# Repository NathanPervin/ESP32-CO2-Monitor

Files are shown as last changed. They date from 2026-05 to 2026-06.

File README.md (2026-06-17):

# CO2 Monitor
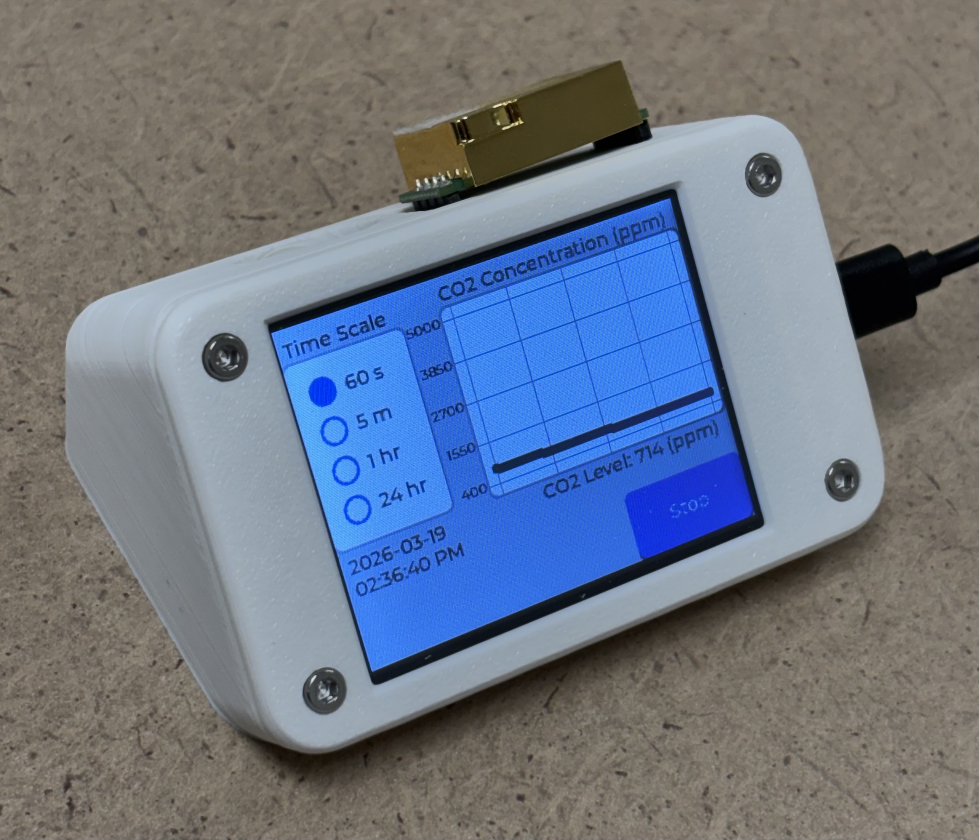
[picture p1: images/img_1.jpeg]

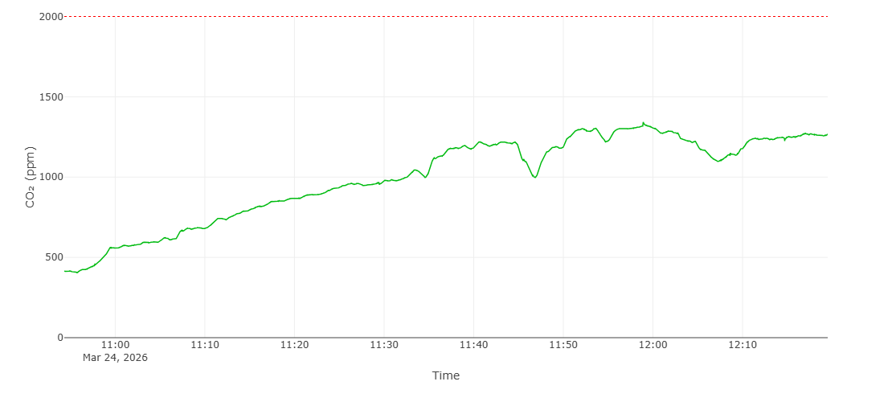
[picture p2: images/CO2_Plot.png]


### Description
An ESP32-based CO2 monitor that logs readings to a SQLite database and displays them through a Django web application.

### Impact
[Studies](https://www.sciencedirect.com/science/article/pii/S036013232300358X) have shown that short-term exposure to high levels of CO2 can reduce cognitive performance and negatively impact learning. Therefore, it is important to be ensure that CO2 levels remain low in an academic setting.

### Components
MH-Z19C CO2 Sensor ([more info](https://www.winsen-sensor.com/d/files/infrared-gas-sensor/mh-z19c-pins-type-co2-manual-ver1_0.pdf)) \
[by EC Buying](https://www.amazon.com/EC-Buying-Monitoring-Concentration-Detection/dp/B0CRKH5XVX)

ESP32 Cheap Yellow Display ([more info](https://www.lcdwiki.com/2.8inch_ESP32-32E_Display))\
[by Hosyond](https://www.amazon.com/gp/product/B0D92C9MMH)

### Features
* Screen automatically sleeps after 5 minutes of inactivity
* Zero the CO2 sensor to 400 ppm by depressing the button for 7 seconds (only do this when outdoors)

### Dependencies
* Django for web app, API endpoint, and SQLite database
* LVGL for ESP-32 GUI
* TFT_eSPI
* XPT2046_Touchscreen
ESP32 CYD GUI configuration files can be found in [this guide](https://randomnerdtutorials.com/lvgl-cheap-yellow-display-esp32-2432s028r)

### Data Collection and Upload

Samples will be taken every 1 second. The timestamp will be updated after each data POST request to keep the timestamps accurate over long periods of time. POST requests will be made every 4 minutes to reduce power usage and live data is already displayed on the CYD. A SQLite database hosted in the cloud will be used to store the data.

#### `POST /api/log/`

Logs one or more CO2 readings to the database.

**Authentication:** Bearer token via `Authorization` header (set `CO2_API_TOKEN` in `.env`)

**Request body:** A single JSON object or an array of objects:
```json
[
  {"mode": "ambient", "building": "COE", "room_number": 306, "unix_timestamp": 1678886400, "CO2_ppm": 750},
  {"mode": "ambient", "building": "COE", "room_number": 306, "unix_timestamp": 1678886401, "CO2_ppm": 760}
]
```

| Field | Type | Max Length | Description |
|---|---|---|---|
| `mode` | string | 50 chars | `"ambient"` or `"session"` |
| `building` | string | 30 chars | Building identifier (e.g. `"COE"`) |
| `room_number` | string | 10 chars | Room number (e.g. "301A")|
| `unix_timestamp` | int |  | Unix timestamp of the reading |
| `CO2_ppm` | int |  | CO2 concentration in parts per million |

**Responses:**

| Status | Meaning |
|---|---|
| `201` | Success — returns `{"success": true, "records_saved": N}` |
| `400` | Malformed JSON or missing field |
| `401` | Missing or invalid token |

### Pinout
| Pin | Use |
|-----|-----|
| IO35 | PWM for CO2 Sensor |
| 5V (UART PORT) | Vin for CO2 Sensor |
| GND | GND for CO2 Sensor |
| GND | GND for button -> CO2 Sensor HD Pin |

### CAD
Modified [ghfisanotti's CYD Case on Thingiverse](https://www.thingiverse.com/thing:7047135), licensed under CC BY-SA 3.0. See CAD folder in this repo for the STL and STEP files. 

### Required Parts and Assembly
* 1x ESP-32 CYD
* 1x MH-Z19C CO2 Sensor
* 2x 1.25mm 4-pin JST to Dupont connectors
* 1x CYD_LID (3D printed)
* 1x CYD_BASE (3D printed)
* 4x M3 heat-set inserts
* 4x M3x8 bolts
* 1x [push button](https://www.amazon.com/Waterproof-Momentary-Button-Switch-Colors/dp/B07F24Y1TB) *optional, for zeroing the sensor
* 1x 5-pin female pin header *optional, for securing the sensor to the base

The 5-pin female pin header is secured by melting the plastic around it with a soldering iron. On the female pin header that the MH-Z19C's HD pin will plug into, solder a wire (this will connect to one pin of the button). Connect the other pin of the button to a GND pin on the CYD.

###  How to run
Clone this repo
```bash
git clone https://github.com/NathanPervin/ESP32-CO2-Monitor.git
```
```bash
cd ESP32-CO2-Monitor
```

Create a virtual environment
```bash
python -m venv venv
```

Start virtual environment
```bash
source venv/bin/activate
```

Install dependencies
```bash
pip install -r requirements.txt
```

Set environment variables in the file Django/CO2_Dashboard/.env, see the .env.example file in that directory for the required variables. Also set the environment variables in testing/.env, see the .env.example file in that folder for the required variables.

To Generate the CO2_API_TOKEN SECRET_KEY you can run the following command twice:
```bash
python -c "import secrets; print(secrets.token_urlsafe(50))"
```
The CO2_API_TOKEN in this .env and in the esp32 secrets.h must match. 

```bash
cd Django
```
create the database tables
```bash
python manage.py migrate
```

Make your account (use these credentials to sign in). To make a standard user account, see the `Miscellaneous Info` section in this document.
```bash
python manage.py createsuperuser
```

Run locally using:
```bash
python manage.py runserver 0.0.0.0:8000
```

If hosting use the following commands:
```bash
python manage.py collectstatic --noinput
```

Create a systemd service so the web app automatically starts on boot.
```bash
sudo nano /etc/systemd/system/co2dashboard.service
```

Copy and Paste (right click), then change the WorkingDirectory to reflect your system's file path. Exit using CTRL+X then `y`, then hit enter.
```
[Unit]
Description=CO2 Dashboard
After=network.target

[Service]
User=root
WorkingDirectory=/path/to/ESP32-CO2-Monitor/Django
ExecStart=/path/to/ESP32-CO2-Monitor/venv/bin/gunicorn
CO2_Dashboard.wsgi:application --bind 127.0.0.1:8000 --workers 1
Restart=always

[Install]
WantedBy=multi-user.target
```
if you are a different linux user than `root`, replace `root` above with the output of `whoami`

Enable and start systemd service:
```bash
sudo systemctl daemon-reload
```

```bash
sudo systemctl enable co2dashboard
```

```bash
sudo systemctl start co2dashboard
```

Check if its running:
```bash
sudo systemctl status co2dashboard
```

Use caddy as a reverse proxy (requires a domain)
```bash
sudo apt update
```

Install [caddy](https://caddyserver.com/docs/install#debian-ubuntu-raspbian)
```bash
sudo apt install -y debian-keyring debian-archive-keyring apt-transport-https curl
curl -1sLf 'https://dl.cloudsmith.io/public/caddy/stable/gpg.key' | sudo gpg --dearmor -o /usr/share/keyrings/caddy-stable-archive-keyring.gpg
curl -1sLf 'https://dl.cloudsmith.io/public/caddy/stable/debian.deb.txt' | sudo tee /etc/apt/sources.list.d/caddy-stable.list
sudo chmod o+r /usr/share/keyrings/caddy-stable-archive-keyring.gpg
sudo chmod o+r /etc/apt/sources.list.d/caddy-stable.list
sudo apt update
sudo apt install caddy
```

Write the Caddyfile:
```bash
nano /etc/caddy/Caddyfile
```

Copy and Paste (right click), then change the example.com domain to your domain, as well as the file path to your system's path to the staticfiles directory within the Django project. Exit using CTRL+X then `y`, then hit enter.
```
example.com {
    handle /static/* {
        uri strip_prefix /static
        root * /path/to/ESP32-CO2-Monitor/Django/staticfiles
        file_server
    }
    reverse_proxy localhost:8000
}
```

restart Caddy
```bash
sudo systemctl reload caddy
```

Remember to update your domain's DNS records to your server's IP. Also ensure your firewall settings allow access to ports 80 (http) and 443 (https), which Caddy listens on by default.

### How to set up ESP32 CYD
Instructions are for the Arduino IDE:

Open the `esp32/CO2Monitor.ino` file in the Arduino IDE.

install the following libraries from the Library Manager within the Arduino IDE:
* `TFT_eSPI` by `Bodmer`
* `XPT2046_Touchscreen` by `Paul Stoffregen`
* `lvgl` by `kiskegabor`

Follow [this tutorial](https://randomnerdtutorials.com/lvgl-cheap-yellow-display-esp32-2432s028r/), just the `Prepare Config Files for TFT_eSPI and LVGL Library` section is required. 

Then, download the program to your esp32.

### Unit Testing
Run the external API unit tests
```bash
cd testing
```
```bash
pytest testing_api.py 
```

Run the Django internal unit tests
```bash
cd Django/
```
```bash
python manage.py test api -v 2
```

### Miscellaneous Info
Create User
```bash
python manage.py shell
```
```bash
from django.contrib.auth.models import User
```

```bash
User.objects.create_user(username='myuser', password='mypassword')
```

Delete User
```bash
User.objects.get(username='myuser').delete()
```

Change `DEFAULT_BUILDING` and `DEFAULT_ROOM` in secrets.h to simply press start to log data for that room without needing to type it in.

CO2 values are POSTed every 240 seconds (4 minutes) with 240 samples. Increasing the number of samples in each POST can cause the POSTs to fail with the serial log of:
```
POST failed: connection refused
```
If you get this error, try to reduce the number of samples sent in each POST by changing the value of `LOG_BUFFER_SIZE` in `esp32/CO2Monitor.ino`.

If you are using GitHub and want the actions to work properly, add your CO2_API_TOKEN and SECRET_KEY (same as your .env file) to your GitHub repository's secrets.

#### Testing Database Entry Labels
* building of 'debug', room 0 for esp32 test insertions (unless overridden in secrets.h)
* building of 'debug', room 1 for unit testing

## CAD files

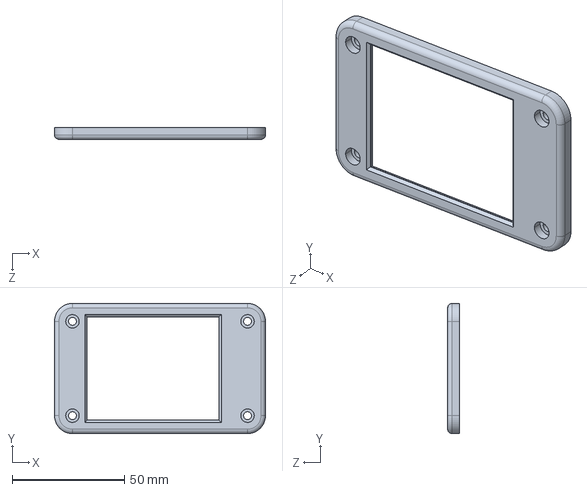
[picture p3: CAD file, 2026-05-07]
CAD/CYD_LID.STEP
94.0 x 58.0 x 5.20 mm

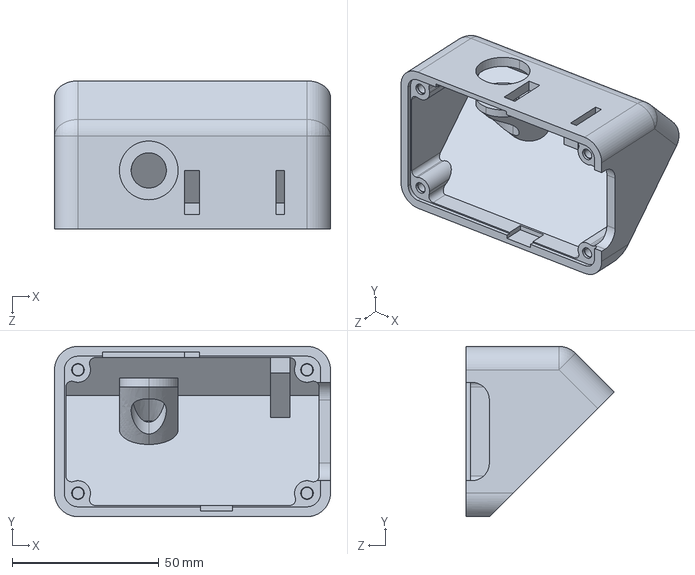
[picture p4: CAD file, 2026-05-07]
CAD/CYD_BASE.STEP
94.0 x 58.0 x 50.5 mm

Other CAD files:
CAD/CYD_BASE.STL
CAD/CYD_LID.STL

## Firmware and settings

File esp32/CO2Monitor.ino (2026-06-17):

// GUI:
// Configuration files and base code from: https://randomnerdtutorials.com/lvgl-cheap-yellow-display-esp32-2432s028r
// LVGL documentation: https://docs.lvgl.io/

// includes for GUI
#include <lvgl.h>
#include <TFT_eSPI.h>
#include <XPT2046_Touchscreen.h>

// includes for WIFI
#include <WiFi.h>
#include <time.h>
#include <secrets.h>
#include <HTTPClient.h>
#include <WiFiClientSecure.h>

/*
    GUI Variables
*/
// Touchscreen pins
#define XPT2046_IRQ 36   // T_IRQ
#define XPT2046_MOSI 32  // T_DIN
#define XPT2046_MISO 39  // T_OUT
#define XPT2046_CLK 25   // T_CLK
#define XPT2046_CS 33    // T_CS

#define TFT_BL 21 // backlight

SPIClass touchscreenSPI = SPIClass(VSPI);
XPT2046_Touchscreen touchscreen(XPT2046_CS, XPT2046_IRQ);

#define SCREEN_WIDTH 240
#define SCREEN_HEIGHT 320

// Touchscreen coordinates: (x, y) and pressure (z)
int x, y, z;

#define DRAW_BUF_SIZE (SCREEN_WIDTH * SCREEN_HEIGHT / 10 * (LV_COLOR_DEPTH / 8))
uint32_t draw_buf[DRAW_BUF_SIZE / 4];

const char* top_text = "CO2 Monitor";
const char* enter_building_text = "Building";
const char* enter_room_number_text = "Room Number";
const char* ambient_text = "Ambient";
const char* session_text = "Session";
const char* CO2_plot_title = "CO2 Concentration (ppm)";
const char* time_scale_text = "Time Scale";

bool is_ambient = true; // default value is to record as an ambient, if false, mode is session

static lv_obj_t* start_screen;
static lv_obj_t* recording_screen;

static lv_obj_t * ta1; // text area for the building input
static lv_obj_t * ta2; // text area for the room input

#define MAX_BUILDING_LENGTH 31  
#define MAX_ROOM_LENGTH 11      

//#define MAX_INPUT_TEXT_LENGTH 50
char building_text[MAX_BUILDING_LENGTH];
char room_text[MAX_ROOM_LENGTH];

static lv_obj_t * chart;
static lv_chart_series_t * ser;

// the width of the x axis, in seconds 
static short int time_scale = 60; 

// determines how many point will be displayed at once,
const short int number_plot_points = 60; 
const short int CO2_plot_rate = 1000; // ms
static short int CO2_min = 400; // ppm
static short int CO2_max = 5000; // ppm

static lv_style_t style_radio;
static lv_style_t style_radio_chk;

const char* time_scales[] = {
  "60 s",
  "5 m",
  "1 hr",
  "24 hr",
  NULL
};

typedef enum {
  t_60s,
  t_5mins,
  t_1hr,
  t_24hrs
} TimeScale;

TimeScale current_time_scale = t_60s;

const int screen_sleep_after_time = 300000; // ms, 5 mins

lv_obj_t * CO2_level_label;
char CO2_level_text[30];

lv_obj_t * time_label;
char time_text[32];

lv_obj_t * error_label;
char error_text[32];

lv_obj_t * wifi_dropdown = NULL;
lv_obj_t * wifi_icon_button;

/*
//  CO2 Sensor Variables
*/
#define CO2_PWM_PIN 35

volatile unsigned long previous_low_start = 0;  // us
volatile unsigned long previous_high_start = 0; //us
volatile unsigned long TL = 0; // us
volatile unsigned long TH = 0; // us

const short int CO2_log_rate = 1000; // ms

/*
    WIFI Variables
*/
const char* ntpServer = "pool.ntp.org";
const long gmtOffset_sec = -18000;   // EST
const int daylightOffset_sec = 3600;  // 1 hour for daylight saving
bool wifi_initialized = false;

unsigned long last_wifi_init_attempt = 0; // timestamp of last attempt
const unsigned long attempt_wifi_init_every = 5000; // ms
static int max_init_attempts = 5;

#define MAX_SSID_LEN 64
#define MAX_PASSWORD_LEN 64

char WIFI_SSID[MAX_SSID_LEN];
char WIFI_PASSWORD[MAX_PASSWORD_LEN];

/*
    System Variables
*/
// buffers that will store the last 60 points
// which are an average of the available time intervals
static int32_t buffer_60secs[number_plot_points];
static int32_t buffer_5min[number_plot_points];
static int32_t buffer_1hr[number_plot_points];
static int32_t buffer_24hrs[number_plot_points];

// store the index where the next value should be placed
int i_60secs = 0;
int i_5mins = 0;
int i_1hr = 0;
int i_24hrs = 0;

// variables to find the average CO2 ppm over an interval
float sum_last_5s_CO2 = 0;
float count_5s = 0;
float sum_last_60s_CO2 = 0;
float count_60s = 0;
float sum_last_1440s_CO2 = 0;
float count_1440s = 0;

const short int ppm_threshold = 2000; // CO2 ppm above this will make the plot line red
static float CO2_value = 0;

bool on_start_screen = false;
bool on_recording_screen = false;

#define LOG_BUFFER_SIZE 240 // 240 JSON lines, 1s per line = 240 minutes of data

// {"mode":"session","building":"","room_number":"","unix_timestamp":1700000000,"CO2_ppm":5000}
// fixed chars:  ~64  +  max building: 30  +  max room: 10  +  null: 1  =  105, use 128 for extra room
#define MAX_JSON_LINE 128
char log_buffer[LOG_BUFFER_SIZE][MAX_JSON_LINE];
int log_buffer_index = 0;

/*
    CO2 Sensor Functions
*/
// Software interrupt on IO35 Change
void ARDUINO_ISR_ATTR read_PWM() {

  // Get level to determine if the ISR was triggered on rising on falling edge
  int level = digitalRead(CO2_PWM_PIN);

  // get the current microseconds since program start or last overflow
  unsigned long now = micros(); 

  // rising edge, the duration of the low time can be calculated by
  // subtracting the previous falling edge's time from the current time
  if (level == HIGH) {
    TL = now - previous_low_start;
    previous_high_start = now;
  } else { 
    // falling edge, the duration of the high time preceding this can be found by 
    // subtracting the previous rising edge's time from the current time
    TH = now - previous_high_start;
    previous_low_start = now;
  }
}

/*
    WIFI Functions
*/
// connects to wifi and configures NTP for unix time retrieval
void initialize_wifi() {
  Serial.printf("Connecting to Wi-Fi %s ...\n", WIFI_SSID);

  // SSID and password must be inside of secrets.h
  WiFi.begin(WIFI_SSID, WIFI_PASSWORD);

  // try to connect to the wifi
  int attempts = 0;
  while (WiFi.status() != WL_CONNECTED && attempts < max_init_attempts) {
    delay(500);
    Serial.print(".");
    attempts++;
  }

  if(WiFi.status() != WL_CONNECTED){
    Serial.println("\nFailed to connect to Wi-Fi");
    wifi_initialized = false;
    error_handler();
    return;
  } 
  else {
    wifi_initialized = true;
    error_handler();
  }

  Serial.println("\nWi-Fi connected!");
  wifi_initialized = true;
  Serial.print("IP address: ");
  Serial.println(WiFi.localIP());

  // Initialize NTP
  configTime(gmtOffset_sec, daylightOffset_sec, ntpServer);
}

// Handles wifi connection attempts if wifi connection fails,
// attempts to estabish a new connection on set intervals until
// a successful connection is made
bool handle_wifi_reinitialization() {
  if (!wifi_initialized) {

    // check that the time interval between connections has passed
    if (millis() - last_wifi_init_attempt >= attempt_wifi_init_every) {
      
      initialize_wifi();
      last_wifi_init_attempt = millis(); // reset timestamp
      return wifi_initialized;
    }
    else { // time interval for new connection attempt has no yet passed
      return false;
    }
  } // wifi is already initialized
  return true;
}

// returns the unix time 
time_t get_unix_time() {

  // if the wifi is not connected, then the unix time cannot be establisheds
  if (!handle_wifi_reinitialization()) return -1;

  time_t now = time(nullptr);
  int retry = 0;
  const int retry_count = 10;

  // ensure unix time is valid, otherwise try again
  while (now < 1000000000 && retry < retry_count) { 
    delay(500);
    now = time(nullptr);
    retry++;
  }

  if(now < 1000000000) return 0;
  return now;
}

/*
    System Functions
*/
// saves a CO2 level and unix timestamp to a JSON string and adds it to the buffer 
// that stores all of the JSON lines prior to sending the POST request
// also calls function that will POST when buffer is full
void log_data(int32_t CO2_ppm, time_t unix_time) {

  // synthesize the JSON string that will be stored in the buffer 
  snprintf(log_buffer[log_buffer_index], MAX_JSON_LINE,
    "{\"mode\":\"%s\",\"building\":\"%s\",\"room_number\":\"%s\",\"unix_timestamp\":%ld,\"CO2_ppm\":%d}",
    is_ambient ? "ambient" : "session",
    building_text,
    room_text,
    (long)unix_time,
    (int)CO2_ppm
  );

  // each time a line is added to the buffer, increment a counter and
  // call function to POST the data when the buffer is full
  log_buffer_index++;
  if (log_buffer_index >= LOG_BUFFER_SIZE) {
    upload_data();
    log_buffer_index = 0;
  }
}

// makes the POST request to the SERVER_URL in secrets.h
// handles inputting the api token into the header for authentification
bool upload_data() {

  // ensure that wifi is connected
  if (!handle_wifi_reinitialization()) {
    Serial.println("Cannot upload: WiFi not connected");
    return false;
  }

  // calculate payload size upfront to avoid reallocation
  int payload_len = 2; // [ ]
  for (int i = 0; i < log_buffer_index; i++) {
    payload_len += strlen(log_buffer[i]);
    if (i < log_buffer_index - 1) payload_len += 1; // comma
  }

  String payload;
  payload.reserve(payload_len + 1);
  payload = "[";
  for (int i = 0; i < log_buffer_index; i++) {
    payload += log_buffer[i];
    if (i < log_buffer_index - 1) payload += ",";
  }
  payload += "]";

  WiFiClientSecure client;
  client.setInsecure();
  HTTPClient http;
  http.begin(client, SERVER_URL);
  http.addHeader("Content-Type", "application/json");
  http.addHeader("Authorization", "Bearer " + String(API_TOKEN));

  Serial.printf("Uploading %d readings...\n", log_buffer_index);
  int response_code = http.POST(payload);

  if (response_code > 0) {
    Serial.printf("POST response: %d\n", response_code);
    Serial.println(http.getString());
    http.end();
    return true;
  } else {
    Serial.printf("POST failed: %s\n", http.errorToString(response_code).c_str());
    http.end();
    return false;
  }
}

// called each time a CO2 value is collected (every 1 second),
// values get averaged and stored in all buffers to allow for
// past data to be displayed for new timescale 
void load_buffers(float CO2_ppm) {
  
  int32_t val = (int32_t)CO2_ppm;
  time_t time = get_unix_time();

  // display nothing to the user if time is not valid
  // usually when wifi isn't initialized yet
  if (time == -1 || time == 0) {
    snprintf(time_text, sizeof(time_text), "");
  } 
  else {
    convert_time(time); // saves time to global var time_text

    // only log the value if we are able to receive a time stamp
    log_data(val, time);
  }

  // load 60 seconds buffer, get next index
  buffer_60secs[i_60secs] = val;
  i_60secs = (i_60secs + 1) % number_plot_points; // index of 60 loops back to 0

  // avoid duplicate plot updates
  if (current_time_scale == t_60s) {
    update_plot();
  }

  // calculate sums and advance counters
  sum_last_5s_CO2 += CO2_ppm;
  count_5s++;
  sum_last_60s_CO2 += CO2_ppm;
  count_60s++;
  sum_last_1440s_CO2 += CO2_ppm;
  count_1440s++;

  // push the last 5 second average into the 5 minute buffer 
  if(count_5s >= 5) {

    int32_t avg = (int32_t)(sum_last_5s_CO2 / count_5s);

    // load buffer, get next index 
    buffer_5min[i_5mins] = avg;
    i_5mins = (i_5mins + 1) % number_plot_points;

    sum_last_5s_CO2 = 0;
    count_5s = 0;
    update_plot();
  }

  // push the last 60 second average into the 1 hour buffer 
  if(count_60s >= 60) {

    int32_t avg = (int32_t)(sum_last_60s_CO2 / count_60s);

    // load buffer, get next index 
    buffer_1hr[i_1hr] = avg;
    i_1hr = (i_1hr + 1) % number_plot_points;

    sum_last_60s_CO2 = 0;
    count_60s = 0;
    update_plot();
  }

  // push the last 1440 second average into the 24 hour buffer 
  if(count_1440s >= 1440) {

    int32_t avg = (int32_t)(sum_last_1440s_CO2 / count_1440s);

    // load buffer, get next index 
    buffer_24hrs[i_24hrs] = avg;
    i_24hrs = (i_24hrs + 1) % number_plot_points;

    sum_last_1440s_CO2 = 0;
    count_1440s = 0;
    update_plot();
  }

}

// clears all buffers and related variables
// used when user creates a new recording session
void clear_buffers() {

  // initialize the buffers so that the plot will be empty on start
  for(int i = 0; i < number_plot_points; i++) {
    buffer_60secs[i] = LV_CHART_POINT_NONE;
    buffer_5min[i] = LV_CHART_POINT_NONE;
    buffer_1hr[i] = LV_CHART_POINT_NONE;
    buffer_24hrs[i] = LV_CHART_POINT_NONE;
  }

  i_60secs = 0;
  i_5mins = 0;
  i_1hr = 0;
  i_24hrs = 0;

  sum_last_5s_CO2 = 0;
  count_5s = 0;
  sum_last_60s_CO2 = 0;
  count_60s = 0;
  sum_last_1440s_CO2 = 0;
  count_1440s = 0;

  log_buffer_index = 0;

}

// Gets the building and room number text from the text areas, checks that the they are valid
bool get_location() {
  const char* building_text_const = lv_textarea_get_text(ta1); 
  const char* room_text_const = lv_textarea_get_text(ta2); 

  // enforce maximum building and room length in case lvgl max
  // input limit fails to avoid buffer overflow when creating JSON lines
  if (strlen(building_text_const) >= MAX_BUILDING_LENGTH) {
    Serial.println("Error: Building name too long!");
    return false;
  }
  if (strlen(room_text_const) >= MAX_ROOM_LENGTH) {
    Serial.println("Error: Room number too long!");
    return false;
  }

  // if no building was entered, use the default from secrets.h
  if (strlen(building_text_const) == 0) {
    strncpy(building_text, DEFAULT_BUILDING, MAX_BUILDING_LENGTH - 1);
  } else {
    strncpy(building_text, building_text_const, MAX_BUILDING_LENGTH - 1);
  }
  building_text[MAX_BUILDING_LENGTH - 1] = '\0';

  // if no room was entered, use the default from secrets.h
  if (strlen(room_text_const) == 0) {
    strncpy(room_text, DEFAULT_ROOM, MAX_ROOM_LENGTH - 1);
  } else {
    strncpy(room_text, room_text_const, MAX_ROOM_LENGTH - 1);
  }
  room_text[MAX_ROOM_LENGTH - 1] = '\0';

  return true;
}

// called when start button is pressed, gets the wifi option that
// the user selected from the dropdown on the start screen
void get_wifi_option() {
  uint16_t sel = lv_dropdown_get_selected(wifi_dropdown);
  if(sel < NUMBER_WIFI_OPTIONS) {
    snprintf(WIFI_SSID, sizeof(WIFI_SSID), "%s", WIFI_SSIDS[sel]);
    snprintf(WIFI_PASSWORD, sizeof(WIFI_PASSWORD), "%s", WIFI_PASSWORDS[sel]);
  }
}

// called to update the error text, handles displaying multiple errors
static void error_handler() {
  if (!wifi_initialized) {
    snprintf(error_text, sizeof(error_text), "%s", "Failed to connect to Wi-Fi");
  }
  else { // TMP, save old errors later
    snprintf(error_text, sizeof(error_text), "%s", "");
  }
}

// Get the Touchscreen data
void touchscreen_read(lv_indev_t * indev, lv_indev_data_t * data) {

  // Checks if Touchscreen was touched, and prints X, Y and Pressure (Z)
  if(touchscreen.tirqTouched() && touchscreen.touched()) {
    
    // turn on backlight to make screen visable
    digitalWrite(TFT_BL, HIGH);

    // Get Touchscreen points
    TS_Point p = touchscreen.getPoint();

    // Calibrate Touchscreen points with map function to the correct width and height
    x = map(p.x, 200, 3700, 1, SCREEN_WIDTH);
    y = map(p.y, 240, 3800, 1, SCREEN_HEIGHT);
    z = p.z;

    data->state = LV_INDEV_STATE_PRESSED;

    // Set the coordinates
    data->point.x = x;
    data->point.y = y;
  }
  else {
    data->state = LV_INDEV_STATE_RELEASED;
  }
}

// called when user clicks into a text area
static void ta_event_cb(lv_event_t * e)
{
  lv_event_code_t code = lv_event_get_code(e);
  lv_obj_t * ta = lv_event_get_target_obj(e);
  lv_obj_t * kb = (lv_obj_t *)lv_event_get_user_data(e);

  // clicked into text area
  if(code == LV_EVENT_FOCUSED) {
    lv_keyboard_set_textarea(kb, ta);
    lv_obj_remove_flag(kb, LV_OBJ_FLAG_HIDDEN);

    // when the user clicks into a text area, the dropdown should be hidden
    // so as to not overlay the keyboard
    if (wifi_dropdown == NULL) return;
    if (!lv_obj_has_flag(wifi_dropdown, LV_OBJ_FLAG_HIDDEN)) {
      lv_obj_add_flag(wifi_dropdown, LV_OBJ_FLAG_HIDDEN);
    } 
  }

  // clicked out of text area
  if(code == LV_EVENT_DEFOCUSED) {
    lv_keyboard_set_textarea(kb, NULL);
    lv_obj_add_flag(kb, LV_OBJ_FLAG_HIDDEN);
  }
}

// Creates text centered at the top of the screen
void lv_top_text(lv_obj_t* screen) {

  lv_obj_t * text_label = lv_label_create(screen);
  lv_label_set_long_mode(text_label, LV_LABEL_LONG_WRAP);    
  lv_label_set_text(text_label, top_text);
  lv_obj_set_width(text_label, 150);    // width of the text (wraps if text is longer than the input number)
  lv_obj_set_style_text_align(text_label, LV_TEXT_ALIGN_CENTER, 0);
  lv_obj_align(text_label, LV_ALIGN_CENTER, 0, -105);
}

// Creates the keyboard when a text area is selected
// Allows the user to enter a building and room number
void lv_keyboard(lv_obj_t* screen) {

  // Create a keyboard, automatically displays when a text box is clicked on
  lv_obj_t * kb = lv_keyboard_create(screen);
  lv_obj_add_flag(kb, LV_OBJ_FLAG_HIDDEN);

  // Enter Building Text (Above the text box)
  lv_obj_t * building_text_label = lv_label_create(screen);
  lv_label_set_long_mode(building_text_label, LV_LABEL_LONG_WRAP);    // Breaks the long lines
  lv_label_set_text(building_text_label, enter_building_text);
  lv_obj_set_width(building_text_label, 150);    // Set smaller width to make the lines wrap
  lv_obj_set_style_text_align(building_text_label, LV_TEXT_ALIGN_LEFT, 0);
  lv_obj_align(building_text_label, LV_ALIGN_TOP_LEFT, 45, 30);

  // text area for the building entry. The keyboard will write here
  ta1 = lv_textarea_create(screen);
  lv_obj_align(ta1, LV_ALIGN_TOP_LEFT, 10, 50);
  lv_obj_add_event_cb(ta1, ta_event_cb, LV_EVENT_ALL, kb);
  lv_textarea_set_placeholder_text(ta1, "COE");
  lv_obj_set_size(ta1, 140, 35);
  lv_textarea_set_max_length(ta1, MAX_BUILDING_LENGTH-1);
  
  // Room Number Text (Above the text box)
  lv_obj_t * room_number_text_label = lv_label_create(screen);
  lv_label_set_long_mode(room_number_text_label, LV_LABEL_LONG_WRAP);    // Breaks the long lines
  lv_label_set_text(room_number_text_label, enter_room_number_text);
  lv_obj_set_width(room_number_text_label, 200);    // Set smaller width to make the lines wrap
  lv_obj_set_style_text_align(room_number_text_label, LV_TEXT_ALIGN_LEFT, 0);
  lv_obj_align(room_number_text_label, LV_ALIGN_TOP_LEFT, 185, 30);

  // text area for the room number, the keyboard will write here
  ta2 = lv_textarea_create(screen);
  lv_obj_align(ta2, LV_ALIGN_TOP_RIGHT, -10, 50);
  lv_obj_add_event_cb(ta2, ta_event_cb, LV_EVENT_ALL, kb);
  lv_textarea_set_placeholder_text(ta2, "306");
  lv_obj_set_size(ta2, 140, 35);
  lv_textarea_set_max_length(ta2, MAX_ROOM_LENGTH-1);

  lv_keyboard_set_textarea(kb, ta1);

}

// Called when the Ambient/Session switch is toggled,
// used for specifying the mode
static void switch_event_handler(lv_event_t * e) {

  lv_event_code_t code = lv_event_get_code(e);
  lv_obj_t * obj = lv_event_get_target_obj(e); 
  LV_UNUSED(obj);
  if(code == LV_EVENT_VALUE_CHANGED) {

    // if its set to "ON", its set to a session, otherwise its set to ambient   
    is_ambient = !(lv_obj_has_state(obj, LV_STATE_CHECKED)); 
  }
}
// Creates the ambient/session toggle switch
// located on the left, below the text areas
void lv_switch(lv_obj_t* screen) {

  // Ambient Text (to the left of the switch)
  lv_obj_t * ambient_text_label = lv_label_create(screen);
  lv_label_set_long_mode(ambient_text_label, LV_LABEL_LONG_WRAP);    // Breaks the long lines
  lv_label_set_text(ambient_text_label, ambient_text);
  lv_obj_set_width(ambient_text_label, 200);    // Set smaller width to make the lines wrap
  lv_obj_set_style_text_align(ambient_text_label, LV_TEXT_ALIGN_LEFT, 0);
  lv_obj_align(ambient_text_label, LV_ALIGN_TOP_LEFT, 10, 95);

  // Session Text (to the right of the switch)
  lv_obj_t * session_text_label = lv_label_create(screen);
  lv_label_set_long_mode(session_text_label, LV_LABEL_LONG_WRAP);    // Breaks the long lines
  lv_label_set_text(session_text_label, session_text);
  lv_obj_set_width(session_text_label, 200);    // Set smaller width to make the lines wrap
  lv_obj_set_style_text_align(session_text_label, LV_TEXT_ALIGN_LEFT, 0);
  lv_obj_align(session_text_label, LV_ALIGN_TOP_LEFT, 135, 95);

  // toggle switch (centered between texts)
  lv_obj_t * sw;
  sw = lv_switch_create(screen);
  lv_obj_align(sw, LV_ALIGN_TOP_LEFT, 80, 90);
  lv_obj_add_event_cb(sw, switch_event_handler, LV_EVENT_ALL, NULL);
  lv_obj_add_flag(sw, LV_OBJ_FLAG_EVENT_BUBBLE);

}
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
void loop() {
  lv_task_handler();  // let the GUI do its work
  lv_tick_inc(5);     // tell LVGL how much time has passed
  delay(5);           // let this time pass

  // CO2 sensor elapsed time
  static unsigned long previous_log_time = 0;
  unsigned long now = millis();

  // CO2 sensor ppm calculation and logging
  if (now - previous_log_time >= CO2_log_rate) { // update every 1 second
    previous_log_time = now;

    // TH + TL should sum to above 4000 us to prevent a divide
    // by zero or negative ppm (can occur while sensor is heating)
    if (TH + TL > 4000) {

      // Using formula from datasheet: Cppm = 5000 * (TH - 2) / (TH + TL - 4),
      // converted to microseconds
      float ppm = 5000.0 * (TH - 2000) / (TH + TL - 4000);
      ppm = constrain(ppm, 400, 5000); // the sensor's range is 400-5000 ppm
      CO2_value = ppm;

      if (on_recording_screen) {
        load_buffers(ppm);
      }
    } else {
      Serial.println("Invalid PWM Received");
    }
  }
  
  // Turns the backlight off after some time of inactivity
  if(lv_disp_get_inactive_time(NULL) > screen_sleep_after_time) {
    digitalWrite(TFT_BL, LOW);
  }

}

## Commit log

2026-06-17 switched to SQLite instead of PostgreSQL
2026-06-17 added https support for esp32 POST
